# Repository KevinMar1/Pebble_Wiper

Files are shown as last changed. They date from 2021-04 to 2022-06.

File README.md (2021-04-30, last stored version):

# Pebble_Wiper
Pebble Wiper for Tool Changing 3D Printers

Check out my Youtube video explaining the Pebble Wiper!
https://youtu.be/EdZrv_zDask

I created these files for my own personal use, but due to widespread interest have posted them here. 
At this time I am the only person to have used this system, and as such am only releasing the files as release candidates for future, more pollished releases once others have been able to inegrate it into their machines.

Included files were modeled in SolidWorks 2019 with a student license, so don't even think about selling them :)

This system uses a single printed part (Pebble_Wiper), a micro servo with dimensions of 22.8x12x31 mm (I use a Hextronik MG-14), 3/5ths of an M5 washer, a standard Brass Brad, and a silicone brush (https://www.amazon.com/gp/product/B08DHJGVC7/ref=ppx_yo_dt_b_search_asin_title?ie=UTF8&psc=1).

Files with the prefix TESTING are separate mechanism and mounting files so you can dial in the offsets to fit the mounting positions on your printer.

I recently added the files for a Pebble Wiper which should work on the E3D Tool Changer / Motion System.

I have included the macro I use to activate the wiper during use. I add the callout of this macro to my tool change gcode in my slicer. I use PrusaSlicer, and cannot speak to the efficacy using other slicers, or printers not running RRF3.

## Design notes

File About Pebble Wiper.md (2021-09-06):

# Pebble_Wiper
Pebble Wiper for Tool Changing 3D Printers

Say goodbye to purge towers and boogers on your prints!

Check out my Youtube video explaining the Pebble Wiper!
https://youtu.be/EdZrv_zDask

I created these files for my own personal use, but due to widespread interest have posted them here. 

Included files were modeled in SolidWorks 2019 with a student license, so don't even think about selling them :)

This system uses a single printed part (Pebble_Wiper), a micro servo with dimensions of 22.8x12x31 mm (I use a KST DS215MG or a Hextronik MG-14), a strip of metallic tape, and a silicone brush

I have included the macro I use to activate the wiper during use. I add the callout of this macro to my tool change gcode in my slicer. I use PrusaSlicer, and cannot speak to the efficacy using other slicers, or printers not running RRF3.

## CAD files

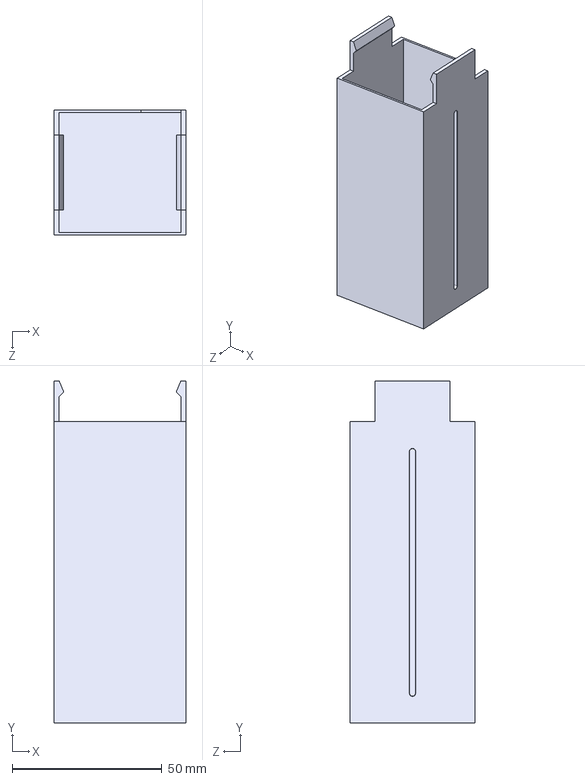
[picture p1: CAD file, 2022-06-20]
Pebble_Bucket.STEP
44.0 x 114.2 x 41.8 mm

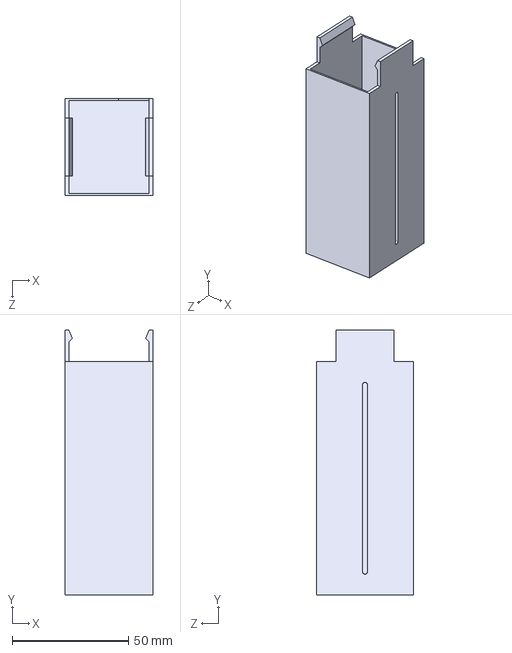
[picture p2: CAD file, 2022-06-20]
HA_Pebble_Bucket.STEP
38.0 x 114.2 x 41.8 mm

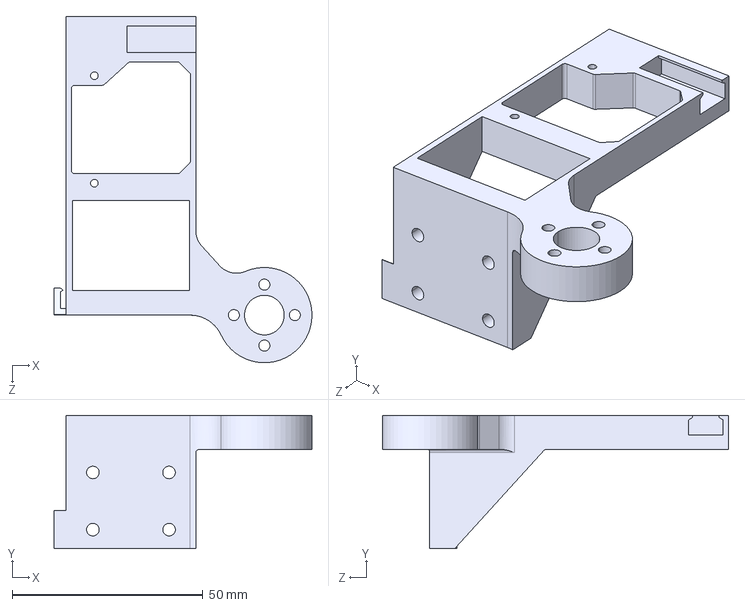
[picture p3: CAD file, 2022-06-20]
HA_Pebble_Wiper_V2.1.STEP
67.7 x 35.0 x 90.9 mm

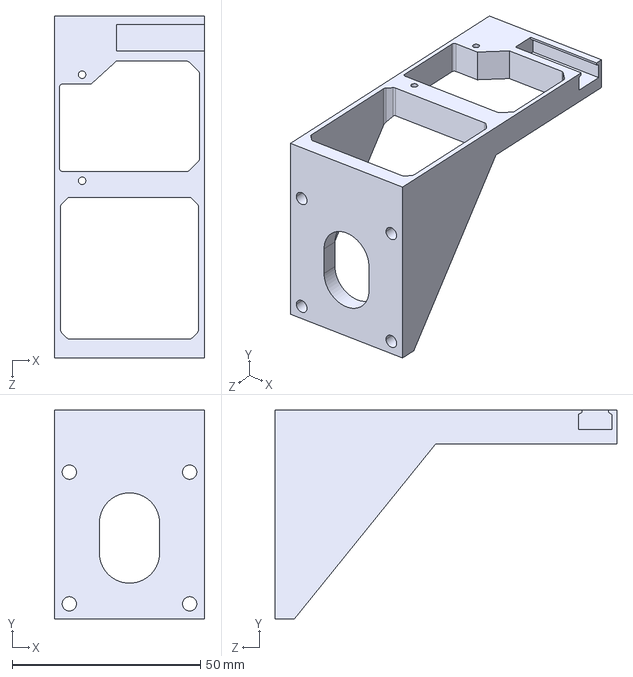
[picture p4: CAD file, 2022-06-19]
Pebble_Wiper_V2.1.STEP
40.0 x 55.5 x 90.9 mm

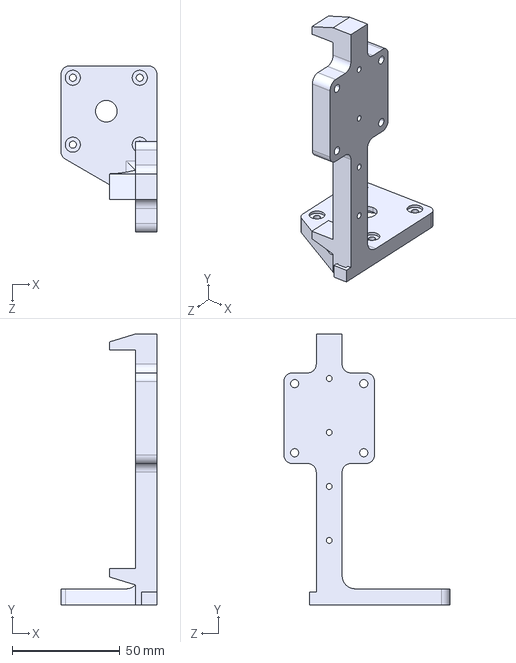
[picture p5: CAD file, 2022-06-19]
PW_V2.1_Stepper_BracketPRUSA.STEP
44.5 x 125.5 x 77.0 mm

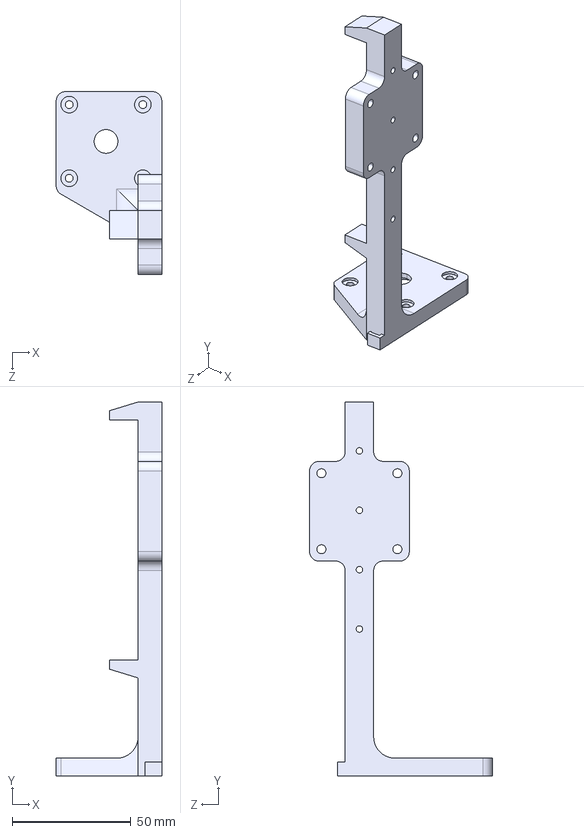
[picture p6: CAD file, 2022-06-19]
PW_V2.1_Stepper_Bracket.STEP
44.5 x 157.5 x 77.0 mm

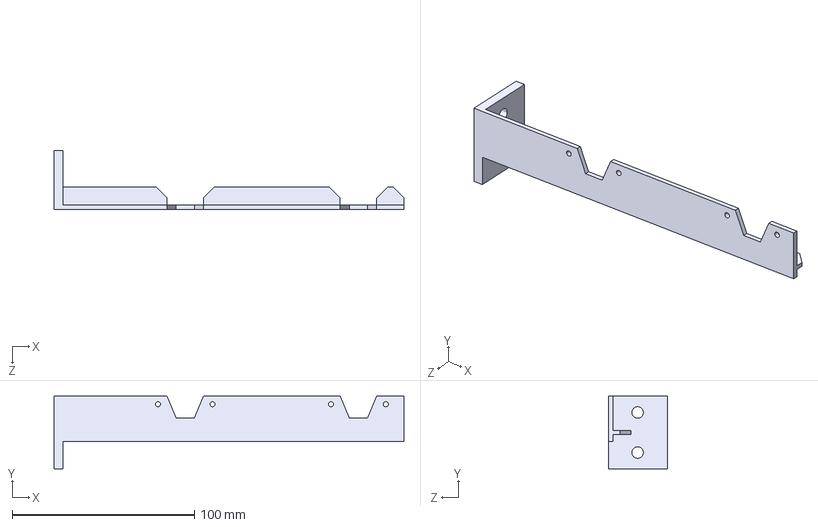
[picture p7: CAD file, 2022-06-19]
T2T3_Dock_Wiper_Bar.STEP
192.0 x 40.0 x 32.4 mm

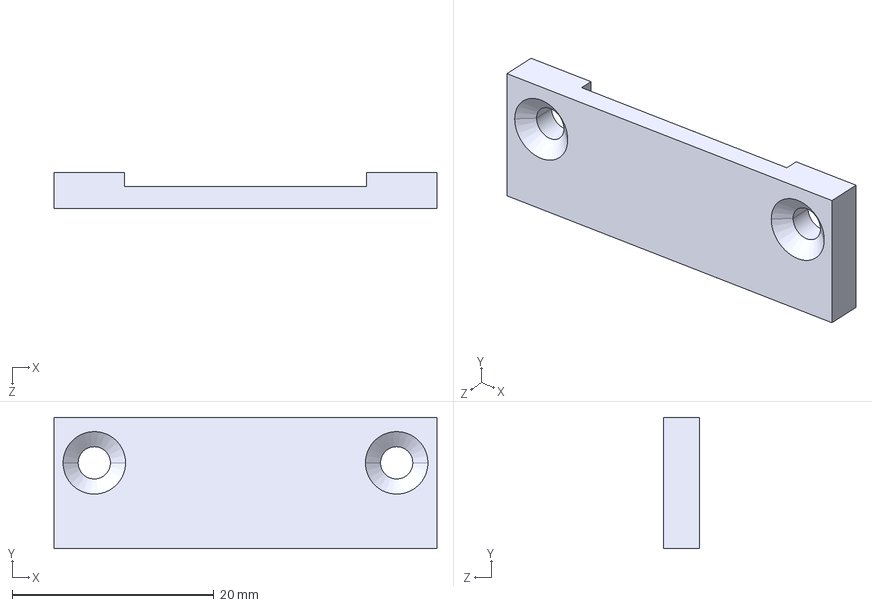
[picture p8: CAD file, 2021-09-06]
Wiper_Bar_Silicone_Holder.STEP
38.0 x 13.0 x 3.60 mm

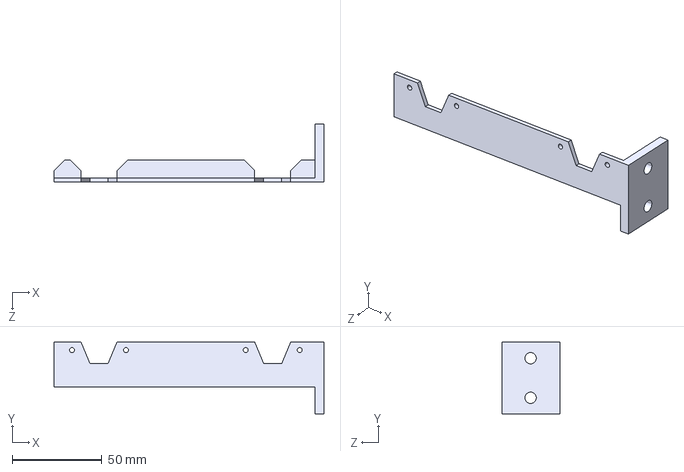
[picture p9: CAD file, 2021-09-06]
T0T1_Dock_Wiper_Bar.STEP
150.0 x 40.0 x 32.4 mm

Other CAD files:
HA_Pebble_Wiper_V2.1PRUSA.STEP
HA_Pebble_Bucket.SLDPRT
HA_Pebble_Wiper_V2.1.SLDPRT
HA_Pebble_Wiper_V2.1.STL
HA_Pebble_Wiper_V2.1PRUSA.SLDPRT
HA_Pebble_Wiper_V2.1PRUSA.STL
HA_Pebble_Wiper_V2.1_PRUSA.SLDPRT
HA_Pebble_Wiper_V2.1_PRUSA.STEP
HA_Pebble_Wiper_V2.1_PRUSA.STL
PW_V2.1_Stepper_Bracket.SLDPRT
PW_V2.1_Stepper_BracketPRUSA.SLDPRT
PW_V2.1_Stepper_BracketPRUSA.STL
Pebble_Bucket.SLDPRT
Pebble_Wiper_V2.1.SLDPRT
Pebble_Wiper_V2.1.STL
T0T1_Dock_Wiper_Bar.SLDPRT
T0T1_Dock_Wiper_Bar.STL
T2T3_Dock_Wiper_Bar.SLDPRT
T2T3_Dock_Wiper_Bar.STL
Wiper_Bar_Silicone_Holder.SLDPRT
Wiper_Bar_Silicone_Holder.STL

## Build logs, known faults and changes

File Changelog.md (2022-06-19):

# Pebble Wiper V2 Changelog
After thousands of wipes, a new version of the Pebble Wiper has been created! 

There are five major improvements in this version:
1. PW V2 no longer deposits the pebbles onto a brass brad. Instead, filament is extruded onto a flat purging platform covered with a metallic strip. The primary advantage which drove this change is that the extruded filament cannot 'fall off' the extrusion zone, as it could with the brad. With the flat extrusion zone, a small, extremely consistent pebble can be created without fail.
2. Although the bargain-bin servo preferred for V1, the Hextronik MG14, worked well, I strived for something even better. The speed of this class of cheap micro servo is sufficient, but there are much faster options on the market. For about $32 I purchased a KST DS215MG servo. Now this is a good sum of money for a tiny servo, but the specs justify it. The MG14 can travel 60° in 0.11sec, but the DS215MG can traverse 60° in a blistering 0.06sec. This best way to describe the difference this makes is the MG14 is like passing a soccer ball (yes, I'm American), and the DS215MG is like rocketing a penalty shot. The increase in speed proved to become a major factor in increasing the already stellar reliability of the Pebble Wiper. I would classify this change as the greatest performance improvement versus V1, and I am therefore only supporting the use of the KST servo for V2. 
3. Another experiment for V2 was the upgrade of the wiping arm. The washer glued on top of the servo arm was not a clean solution, and plastic would occasionally stick to this wiping mechanism. After some searching, I found a metal servo arm for the DS215MG. While the plastic servo arm which comes with the DS215MG proved to be a marked upgrade by itself when compared to the arm+washer used with the MG14, the metal servo arm takes the mechanism that one step further. Plastic does not like to stick to the anodized metal servo arm the same way it likes to stick to the plastic servo arms which come with the servos. In addition, the metal arm does not deform when wiping with even the highest temperature filaments, and will not melt when in contact with your nozzle, if that ever happens. 
4. Lastly, I moved the silicone wiping brush slightly into the path of the wiping arm. This ensures that even if filament becomes stuck to the arm during a wipe, it should not be dragged back onto the purging platform where it could become a booger on the nozzle, and then be deposited onto your model. This extension of the silicone brush keeps your wiping arm clean, and continues to serve the purpose of ensuring a clean nozzle is leaving the Pebble Wiper as it heads over to your print!
5. Integrating with either René Jurack or Greg Holloway's Height Adjustable Brush systems, the Pebble Wiper can now be used on machines with tools of varying height offsets. For example, on a machine with an E3D V6 and an E3D Volcano, the position of the Pebble Wiper can remain at the proper heights in relation to the nozzle through a range of approximately 50mm.

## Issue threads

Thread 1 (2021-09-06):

Add a version with a slot for a brass plate

marconovino, 2021-09-06:
Since the aluminum tape is unavailable/too expensive in like half the world it would be great to have a version that can use a 3mm thick brass plate as a pebble surface

KevinMar1, 2021-09-06:
I cannot account for everybody's specific situation, that's why I included the SLDPT and STEP files so people can modify it to suite their needs.

Closed 2021-09-06.

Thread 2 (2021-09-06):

Reinforce the servo mount

marconovino, 2021-09-06:
Add ribs or some other reinforcement, when the PW jams it could snap the mount

KevinMar1, 2021-09-06:
Never had this issue; and it would be better to snap the mount than to snap the servo.

Closed 2021-09-06.

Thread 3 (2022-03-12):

HA_Pebble_Wiper_V2.1_KST215PRUSA.STL the wrong version

RhepTheSpring, 2022-03-12:
I imported the prusa stl version to fit there z axis lead screw, the diameter of the support is 22mm as apposed to 25mm which is the prusa OD nut size

KevinMar1, 2022-03-13:
Hmm, I’ll take a look at the issue.

Thanks for the heads up

> On Mar 12, 2022, at 8:51 AM, RhepTheSpring ***@***.***> wrote:
>
> the

Closed 2022-04-02.

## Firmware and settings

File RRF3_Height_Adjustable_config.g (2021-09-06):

M569 P0.5 S0 D2						; Drive 5 direction | A

M584 A5							; Axis to driver mapping 

M208 A0:55						; Set axis software limits and min/max switch-triggering positions

M350 A16 I1						; Configure microstepping with interpolation

M906 A600 I20						; Set motor currents (mA) and idle percent A400
M203 A6000						; Max speeds (mm/min)
M201 A1200						; Max Accelerations (mm/s^2)
M566 A360						; Max jerk (mm/min)

M92 A360						; Steps/mm 

M915 A S5 F0 H200 R0					; A Stall Detection

M950 F7 C"^0.out9" Q600					;Wipe Servo
M106 P7 C"Wipe" 					;Wipe Servo
